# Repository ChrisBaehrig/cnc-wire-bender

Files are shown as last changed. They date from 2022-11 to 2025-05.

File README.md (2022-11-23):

# cnc-wire-bender
Open Source Project by ChrisBaehrig for a cnc controlled wire bender based on an arduino and cad fusion360 file

## Concept and changes 
The Hardware bases on the Idea of Pensas diwire bender (https://code.google.com/archive/p/diwire/ License: https://creativecommons.org/licenses/by-sa/3.0/us/) and the Project from HowtoMechatronics Wire Bender (https://howtomechatronics.com/projects/arduino-3d-wire-bending-machine/). 
Power electronic ist improved to for more durability and stronger wires. 
Software is new developed for the end to end production from the cad tool fusion 360 until the cnc wire bending

## Workflow and Architecture




## Frontend GUI Terminal
  <kbd>  </kbd>
  <kbd>   </kbd>
  <kbd>   </kbd>

## Overview GCode commands

### G1 single Axis 
Example: ```N4 G01 X10 I1500 Y2 J1200 Z9 K1300```
  - Row: 4 
  - Command: G1
  - X-Axis: Angle: +10 degree, Speed: 1500 steps / sec
  - Y-Axis: Angle: +2 degree, Speed: 1200 steps / sec
  - Z-Axis: Angle: +9 degree, Speed: 1300 steps / sec

### G2 multi Axis similstaniouly --> tbd

### G3 Circle bending 
Example: ```N4 G03 R100 Y10 Z10 L200 I1500 J1200 K1300 P0.1``` --> tbd
  - Row: 4 
  - Command: G3
  - R: Radius + 10mm clockwise, Speed: 1500 steps / sec
  - Y: Y-Angle: +10 degree, Speed: 1200 steps / sec
  - Z: Z-Angle: +10 degree, Speed: 1500 steps / sec
  - L: Absolute Lenght: 200mm
  - (Optional) Correctionfactor P0.1 = 10% overbending

Example: ```N4 G03 R100 Y10 Z10 H2.5 I1500 J1200 K1300```
  - H: count of turns (2.5 turns)

### G4 Wait 
Example: ```G04 H5```
  - Wait 5 sec

### G5 Wait for Event --> tbd

### G28 Go Home
Example: ```G28```
  - Drive to home position
  

### G92 Set all Positions to Null
Example: ```G92```
  - Set all Positions to Null to Calibrate 

### M10 Drive Wire to bender
Example: ```M10```
  - drive feeder 2000 steps 

### M11 Drive Wire for manuel cutting
Example: ```M11```
  - drive feeder 200 steps 

### M20 Pin down
Example: ```M20```
  - Moves Pin down

### M21 Pin up
Example: ```M21```
  - Moves Pin up

### M30 Program end
Example: ```M30```

## Serial connection API Commands: 

| variable 	| < 	| row 	| , 	| command 	| , 	| value1 	 | , 	| value2 	| , 	| value3 	| , 	| value4 	| > 	|
|---	|---	|-----	|---	|---	|---	|--- 	|---	|--- 	|---	|---	|---	|---	|---	|
| datatyp 	| 	| int 	| 	| int 	| 	| long 	| 	| long 	| 	| long 	| 	| float  	| 	|
| X-Axis (bend) 	| < 	| 1 	| , 	| 1 	| , 	| steps 	 | , 	| steps/sec 	| , 	| 0 	| , 	| 0.0 	| > 	|
| Y-Axis (feed) 	| < 	| 1 	| , 	| 2 	| , 	| steps 	 | , 	| steps/sec 	| , 	| 0 	| , 	| 0.0 	| > 	|
| Z-Axis (turn) 	| < 	| 1 	| , 	| 3 	| , 	| steps 	| , 	| steps/sec 	| , 	| 0 	| , 	| 0.0 	| > 	|
| p-Axis (pin) 	| < 	| 1 	| , 	| 4 	| , 	| degree 	| , 	| 0 	| , 	| 0 	| , 	| 0.0 	| > 	|
| Wait for taster	| < 	| 1 	| , 	| 5 	| , 	| 0 	 | , 	| 0 	| , 	| 0 	| , 	| 0.0 	| > 	|
| tbd 	| < 	| 1 	| , 	| 6 	| , 	| 0 	 | , 	| 0 	| , 	| 0 	| , 	| 0.0 	| > 	|
| tbd 	| < 	| 1 	| , 	| 7 	| , 	| 0 	 | , 	| 0 	| , 	| 0 	| , 	| 0.0 	| > 	|
| wait in ms 	| < 	| 1 	| , 	| 8 	| , 	| ms 	 | , 	| 0 	| , 	| 0 	| , 	| 0.0 	| > 	|
| switch debug 	| < 	| 1 	| , 	| 9 	| , 	| 1=ON 0=OFF	| , 	| 0 	| , 	| 0 	| , 	| 0.0 	| > 	|

Examples: 
```<123, 1, 100, 2000, 0, 0>```

```<1,4,160,0>``` Pin oben ```<1,4,50,0>``` Pin unten

## Changelog
### [1.0.0] - 2022-10-10

- Initial release

## Acknowledgements

Many thanks to

- [Pensas diwire bender](https://code.google.com/archive/p/diwire/) for the development the first bender
- [How to Mechatronics](https://howtomechatronics.com/projects/arduino-3d-wire-bending-machine/) for a lot of improvments

## Disclaimer
The Projekt is distributed in the hope that it will be useful, but WITHOUT ANY WARRANTY; without even the implied warranty of MERCHANTABILITY or FITNESS FOR A PARTICULAR PURPOSE.

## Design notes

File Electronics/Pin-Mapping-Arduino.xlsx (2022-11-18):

Pin Number | Pin Name | Mapped Pin Name | Anschlussbezeichnung | Farbe | Ziel | Ziel-Pin
97 | PF0 ( ADC0 ) | Analog pin 0
96 | PF1 ( ADC1 ) | Analog pin 1
95 | PF2 ( ADC2 ) | Analog pin 2
94 | PF3 ( ADC3 ) | Analog pin 3
93 | PF4 ( ADC4/TMK ) | Analog pin 4
92 | PF5 ( ADC5/TMS ) | Analog pin 5
91 | PF6 ( ADC6 ) | Analog pin 6
90 | PF7 ( ADC7 ) | Analog pin 7
89 | PK0 ( ADC8/PCINT16 ) | Analog pin 8 | potiServo_input | rot | Sub-D | 2
88 | PK1 ( ADC9/PCINT17 ) | Analog pin 9 | potiFeeder_input | orange | Sub-D | 3
87 | PK2 ( ADC10/PCINT18 ) | Analog pin 10 | potiZaxis_input | gelb | Sub-D | 4
86 | PK3 ( ADC11/PCINT19 ) | Analog pin 11 | potiBender_input | grün | Sub-D | 5
85 | PK4 ( ADC12/PCINT20 ) | Analog pin 12
84 | PK5 ( ADC13/PCINT21 ) | Analog pin 13
83 | PK6 ( ADC14/PCINT22 ) | Analog pin 14
82 | PK7 ( ADC15/PCINT23 ) | Analog pin 15
98 | AREF | Analog Reference
2 | PE0 ( RXD0/PCINT8 ) | Digital pin 0 (RX0)
3 | PE1 ( TXD0 ) | Digital pin 1 (TX0)
6 | PE4 ( OC3B/INT4 ) | Digital pin 2 (PWM)
7 | PE5 ( OC3C/INT5 ) | Digital pin 3 (PWM)
1 | PG5 ( OC0B ) | Digital pin 4 (PWM)
5 | PE3 ( OC3A/AIN1 ) | Digital pin 5 (PWM)
15 | PH3 ( OC4A ) | Digital pin 6 (PWM)
16 | PH4 ( OC4B ) | Digital pin 7 (PWM)
17 | PH5 ( OC4C ) | Digital pin 8 (PWM)
18 | PH6 ( OC2B ) | Digital pin 9 (PWM)
23 | PB4 ( OC2A/PCINT4 ) | Digital pin 10 (PWM)
24 | PB5 ( OC1A/PCINT5 ) | Digital pin 11 (PWM)
25 | PB6 ( OC1B/PCINT6 ) | Digital pin 12 (PWM)
26 | PB7 ( OC0A/OC1C/PCINT7 ) | Digital pin 13 (PWM)
64 | PJ1 ( TXD3/PCINT10 ) | Digital pin 14 (TX3) | LED_output (defekt: Spannung liegt an) | lila | Sub-D | 7
63 | PJ0 ( RXD3/PCINT9 ) | Digital pin 15 (RX3) | SchalterModus_PullUP! | blau | Sub-D | 6
13 | PH1 ( TXD2 ) | Digital pin 16 (TX2) | TasterAutomatik_PullUP! | grau | Sub-D | 8
12 | PH0 ( RXD2 ) | Digital pin 17 (RX2)
46 | PD3 ( TXD1/INT3 ) | Digital pin 18 (TX1)
45 | PD2 ( RXDI/INT2 ) | Digital pin 19 (RX1)
44 | PD1 ( SDA/INT1 ) | Digital pin 20 (SDA)
43 | PD0 ( SCL/INT0 ) | Digital pin 21 (SCL)
78 | PA0 ( AD0 ) | Digital pin 22
77 | PA1 ( AD1 ) | Digital pin 23
76 | PA2 ( AD2 ) | Digital pin 24
75 | PA3 ( AD3 ) | Digital pin 25
74 | PA4 ( AD4 ) | Digital pin 26 | Bender_PUL | - | Platine
73 | PA5 ( AD5 ) | Digital pin 27 | Bender_DIR | - | Platine
72 | PA6 ( AD6 ) | Digital pin 28 | Zaxis_PUL | - | Platine
71 | PA7 ( AD7 ) | Digital pin 29 | Zaxis_DIR | - | Platine
60 | PC7 ( A15 ) | Digital pin 30 | Feeder1_PUL | - | Platine
59 | PC6 ( A14 ) | Digital pin 31 | Feeder1_DIR | - | Platine
58 | PC5 ( A13 ) | Digital pin 32 | Feeder2_PUL | - | Platine
57 | PC4 ( A12 ) | Digital pin 33 | Feeder2_DIR | - | Platine
56 | PC3 ( A11 ) | Digital pin 34 | Feeder3_PUL | - | Platine
55 | PC2 ( A10 ) | Digital pin 35 | Feeder3_DIR | - | Platine
54 | PC1 ( A9 ) | Digital pin 36 | ServoData_output | - | Platine
53 | PC0 ( A8 ) | Digital pin 37 | Endschalter_input | - | Platine
50 | PD7 ( T0 ) | Digital pin 38
70 | PG2 ( ALE ) | Digital pin 39
52 | PG1 ( RD ) | Digital pin 40 | rs | - | LCD | 4
51 | PG0 ( WR ) | Digital pin 41 | en | - | LCD | 6
42 | PL7 | Digital pin 42 | d0 | - | LCD | 7
41 | PL6 | Digital pin 43 | d1 | - | LCD | 8
40 | PL5 ( OC5C ) | Digital pin 44 (PWM) | d2 | - | LCD | 9
39 | PL4 ( OC5B ) | Digital pin 45 (PWM) | d3 | - | LCD | 10
38 | PL3 ( OC5A ) | Digital pin 46 (PWM) | d4 | - | LCD | 11
37 | PL2 ( T5 ) | Digital pin 47 | d5 | - | LCD | 12
36 | PL1 ( ICP5 ) | Digital pin 48 | d6 | - | LCD | 13
35 | PL0 ( ICP4 ) | Digital pin 49 | d7 | - | LCD | 14
22 | PB3 ( MISO/PCINT3 ) | Digital pin 50 (MISO)
21 | PB2 ( MOSI/PCINT2 ) | Digital pin 51 (MOSI)
20 | PB1 ( SCK/PCINT1 ) | Digital pin 52 (SCK)
19 | PB0 ( SS/PCINT0 ) | Digital pin 53 (SS)
11 | GND | GND | - | schwarz | Sub-D | 10
32 | GND | GND | - | - | LCD | 1/3/5/16
62 | GND | GND
81 | GND | GND
99 | GND | GND
30 | RESET | RESET
10 | VCC | VCC | - | braun | Sub-D | 1
31 | VCC | VCC | - | - | LCD | 2/15
61 | VCC | VCC
80 | VCC | VCC
100 | AVCC | VCC
34 | XTAL1 | XTAL1
33 | XTAL2 | XTAL2
4 | PE2 ( XCK0/AIN0 )
8 | PE6 ( T3/INT6 )
9 | PE7 ( CLKO/ICP3/INT7 )
14 | PH2 ( XCK2 )
27 | PH7 ( T4 )
28 | PG3 ( TOSC2 )
29 | PG4 ( TOSC1 )
47 | PD4 ( ICP1 )
48 | PD5 ( XCK1 )
49 | PD6 ( T1 )
65 | PJ2 ( XCK3/PCINT11 )
66 | PJ3 ( PCINT12 )
67 | PJ4 ( PCINT13 )
68 | PJ5 ( PCINT14 )
69 | PJ6 ( PCINT 15 )
79 | PJ7

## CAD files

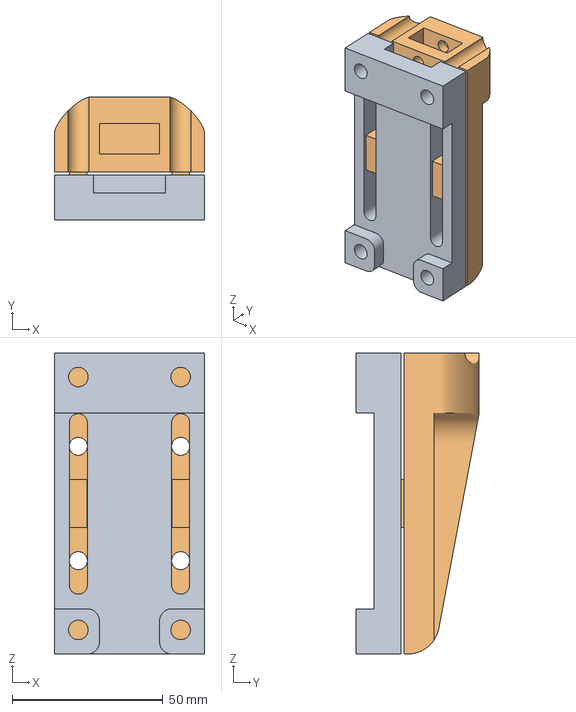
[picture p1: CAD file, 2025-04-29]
Mechanical_parts/Gegenhalter-Vorschub v8.3mf
50.0 x 41.0 x 100.0 mm
Körper1
Körper3

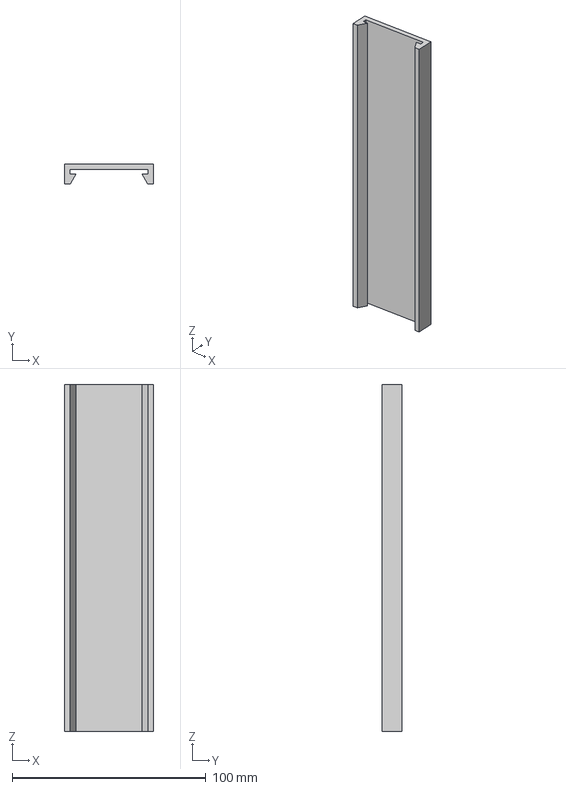
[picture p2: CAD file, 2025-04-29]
Mechanical_parts/Kabelkanaldeckel v1.3mf
46.0 x 10.5 x 179.0 mm

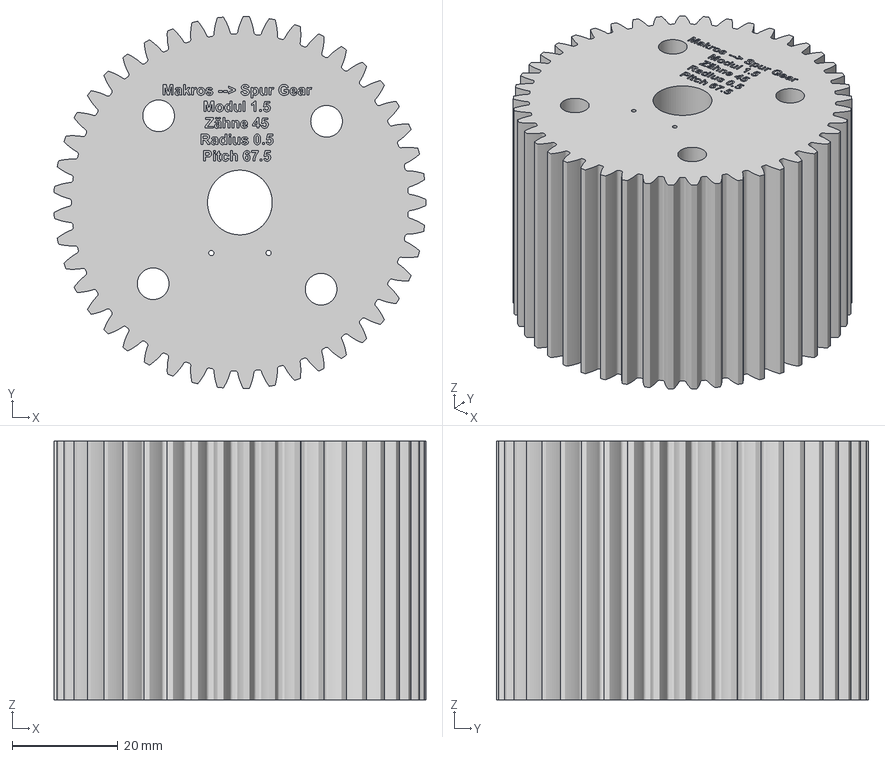
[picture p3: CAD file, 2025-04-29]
Mechanical_parts/Antriebszahnrad-Bieger v14.3mf
70.4 x 70.5 x 49.0 mm

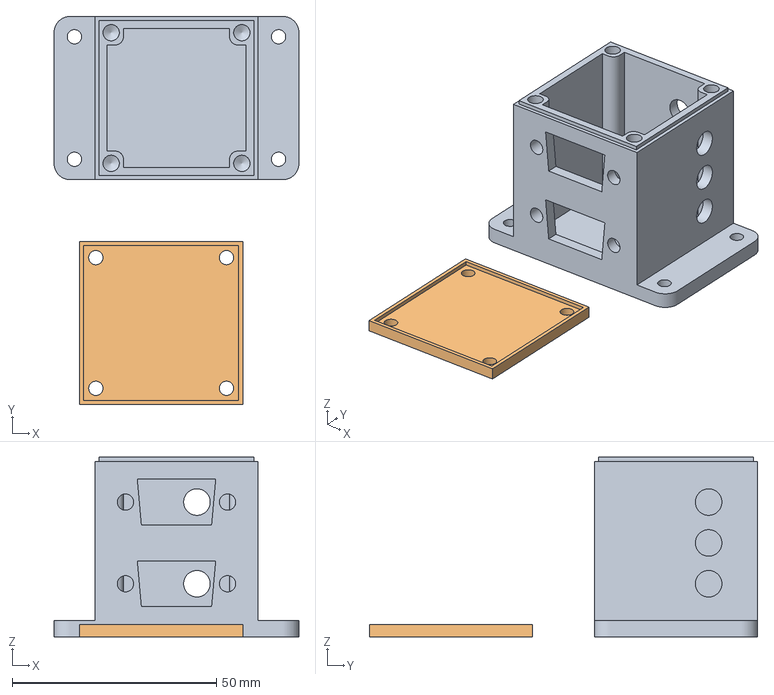
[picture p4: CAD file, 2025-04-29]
Mechanical_parts/Steckerbock-Basis v4.3mf
60.0 x 95.1 x 44.0 mm
Körper1 x 2

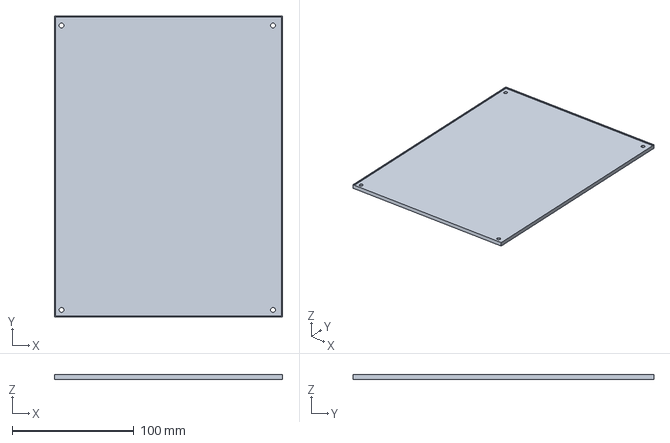
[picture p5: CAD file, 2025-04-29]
Mechanical_parts/Schaltkasten deckel v2.3mf
187.6 x 247.6 x 4.00 mm

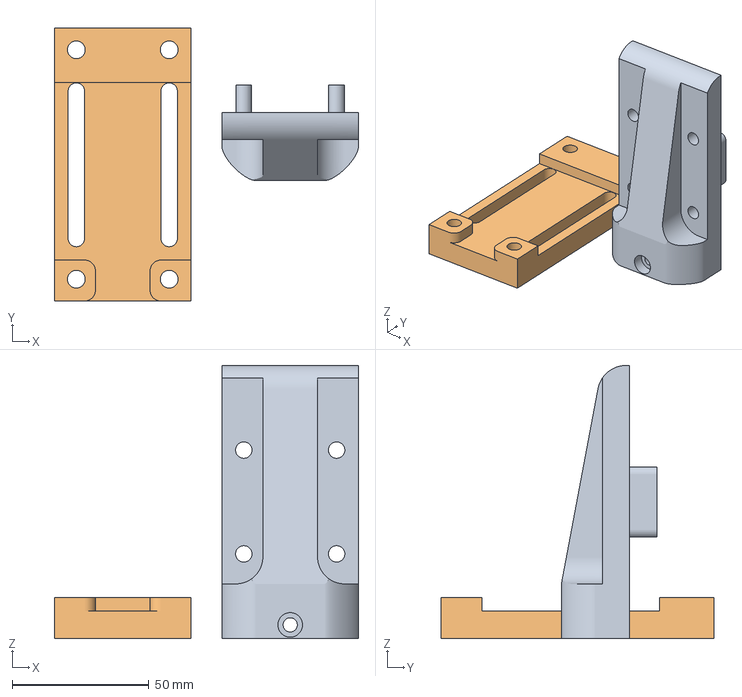
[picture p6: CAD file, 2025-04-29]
Mechanical_parts/Z-Achsengegenhalter.3mf
111.3 x 100.0 x 100.0 mm
Komponente1
Körper1

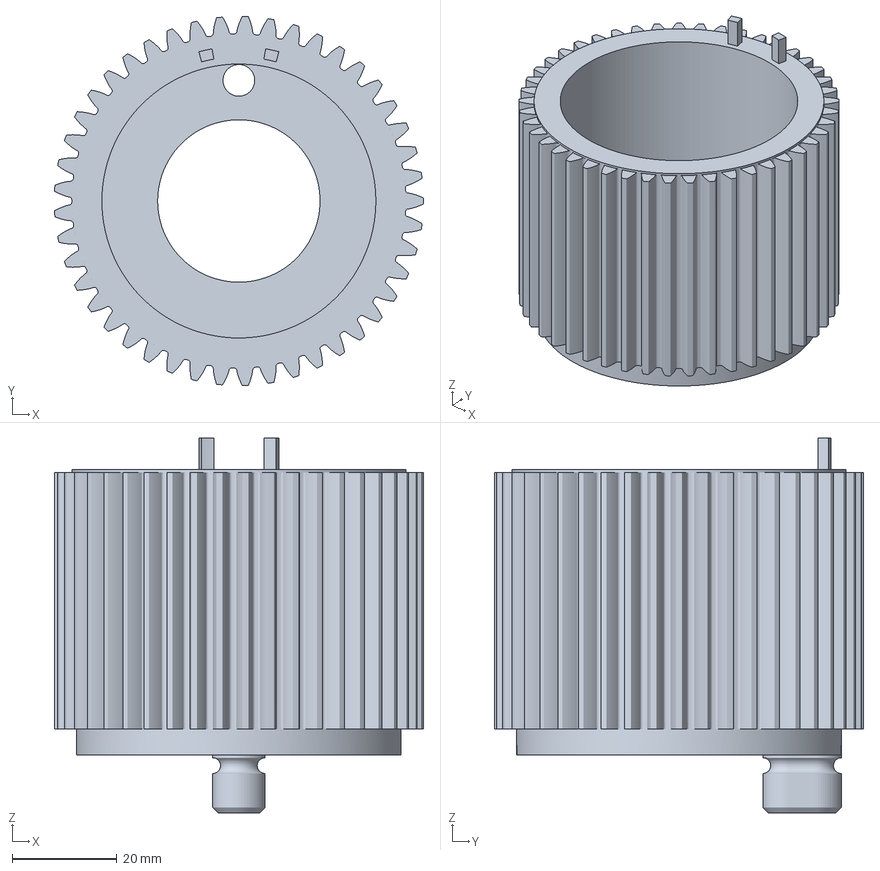
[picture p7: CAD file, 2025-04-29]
Mechanical_parts/Biegezahnrad v17.3mf
70.4 x 70.5 x 71.5 mm

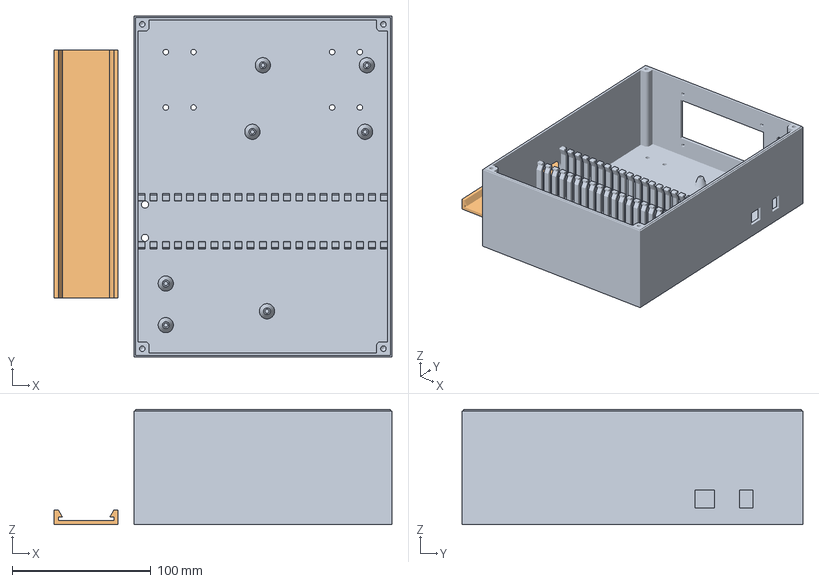
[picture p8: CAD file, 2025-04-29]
Mechanical_parts/Schaltkasten.3mf
243.5 x 246.0 x 83.0 mm
Körper1 x 2

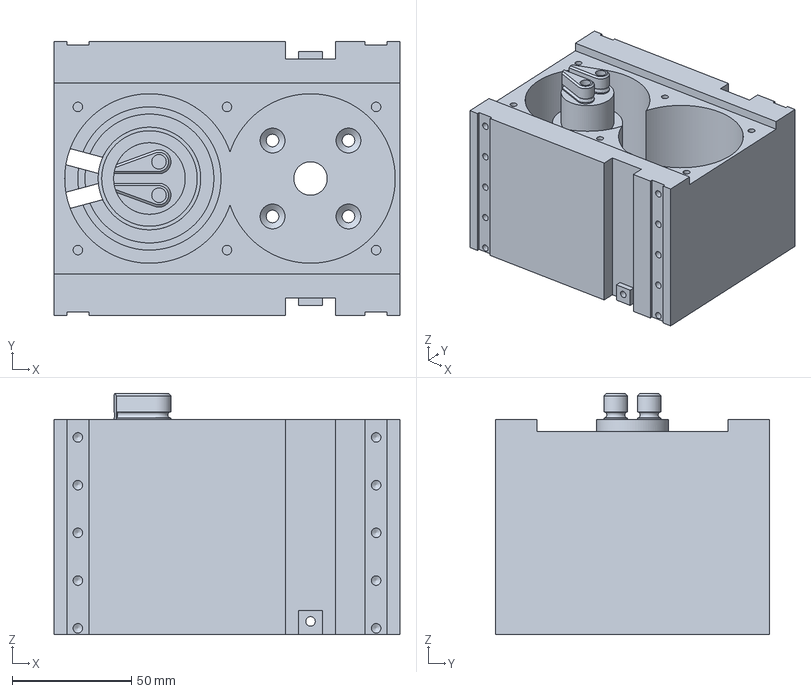
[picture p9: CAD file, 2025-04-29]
Mechanical_parts/Zahnradhalter v37.3mf
145.0 x 115.0 x 101.0 mm

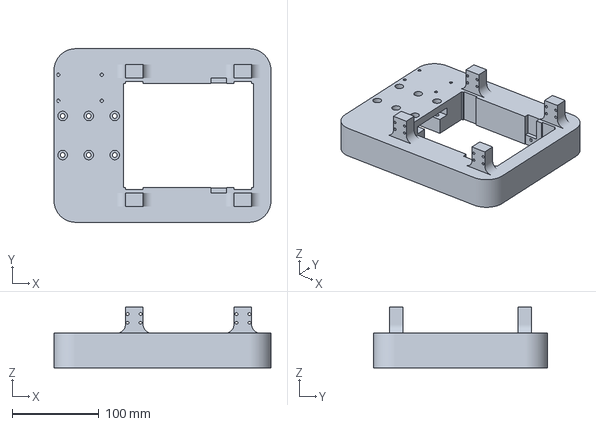
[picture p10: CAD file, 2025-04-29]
Mechanical_parts/Biegehauptplatte v29.3mf
250.0 x 200.0 x 70.0 mm

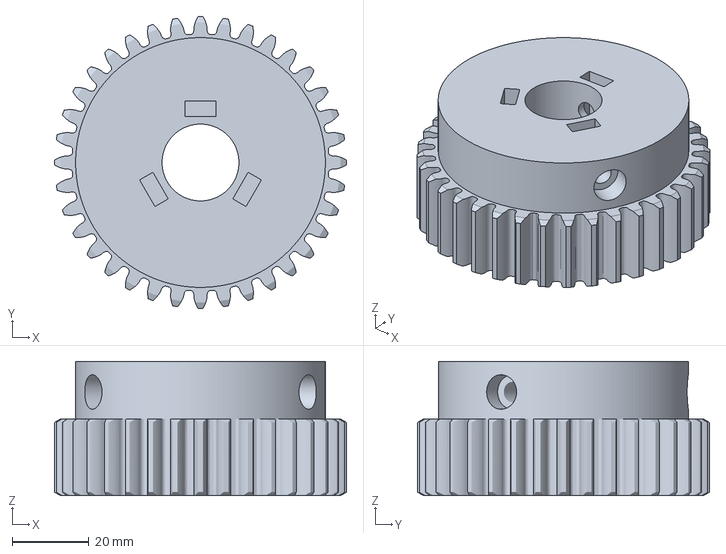
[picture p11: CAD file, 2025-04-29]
Mechanical_parts/Zahnrad Welle v2.3mf
76.0 x 76.0 x 35.0 mm

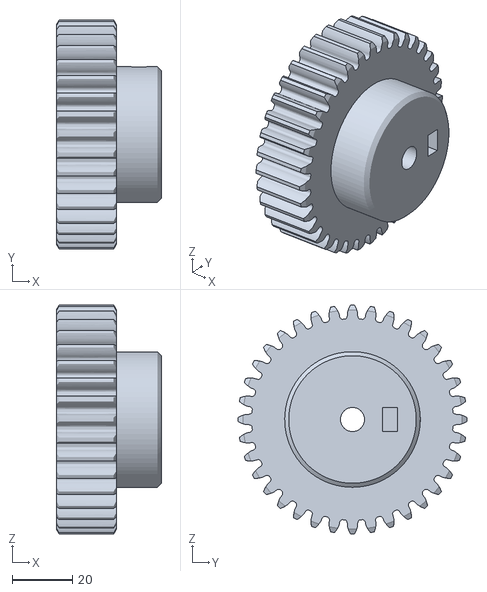
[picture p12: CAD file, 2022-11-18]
Mechanical_parts/Zahnrad Z-Motor.stl
35.0 x 76.0 x 76.0

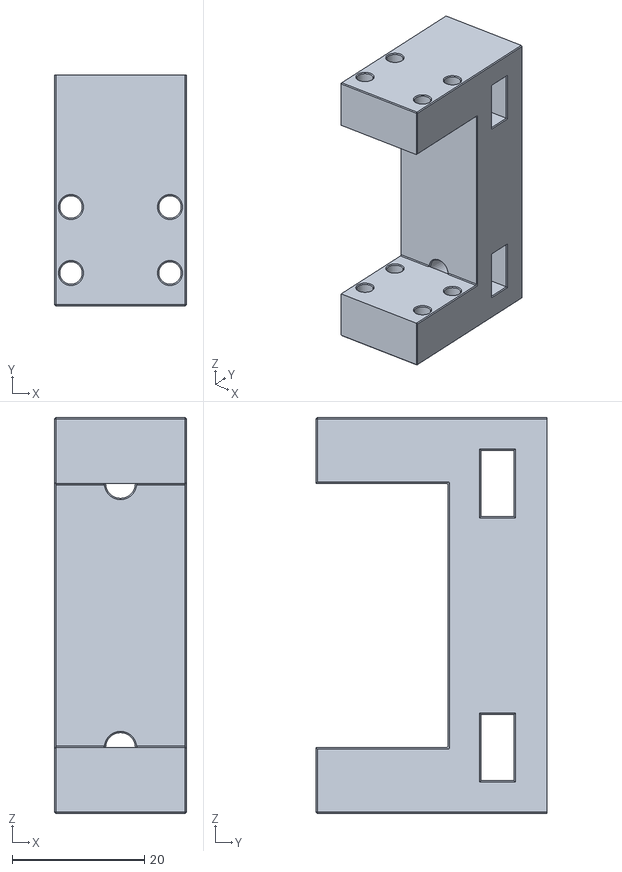
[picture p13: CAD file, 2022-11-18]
Mechanical_parts/Schlitten-Halter v4.stl
20.0 x 35.0 x 60.0

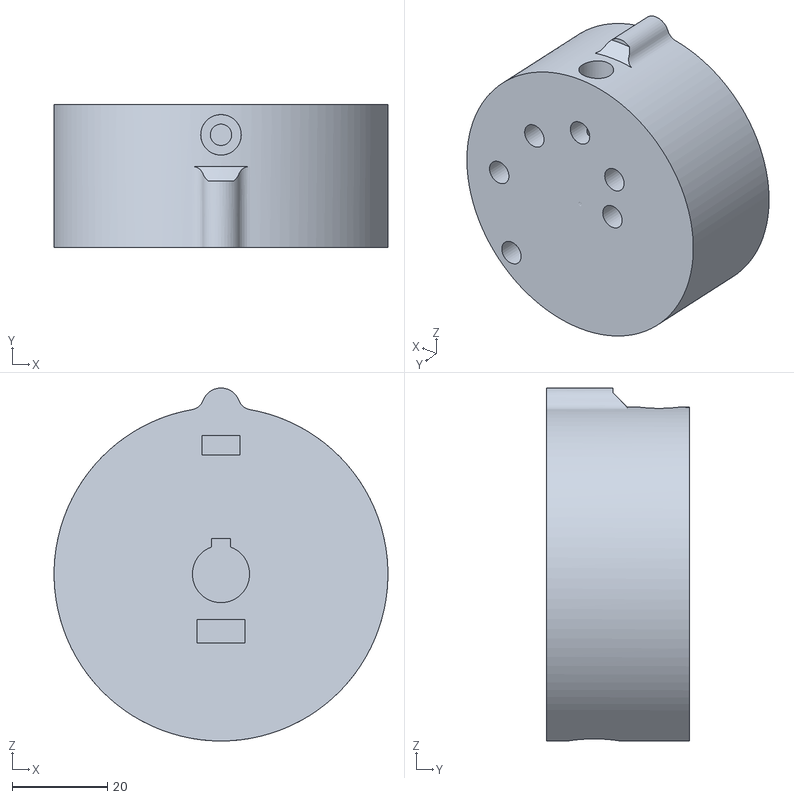
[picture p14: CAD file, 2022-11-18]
Mechanical_parts/Biegerad v5.stl
70.0 x 30.0 x 74.0

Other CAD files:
Mechanical_parts/Schlitten-Halter-Heber v2.stl
Mechanical_parts/Düse v5.stl
Mechanical_parts/Gegenhalter-Vorschub v6.3mf

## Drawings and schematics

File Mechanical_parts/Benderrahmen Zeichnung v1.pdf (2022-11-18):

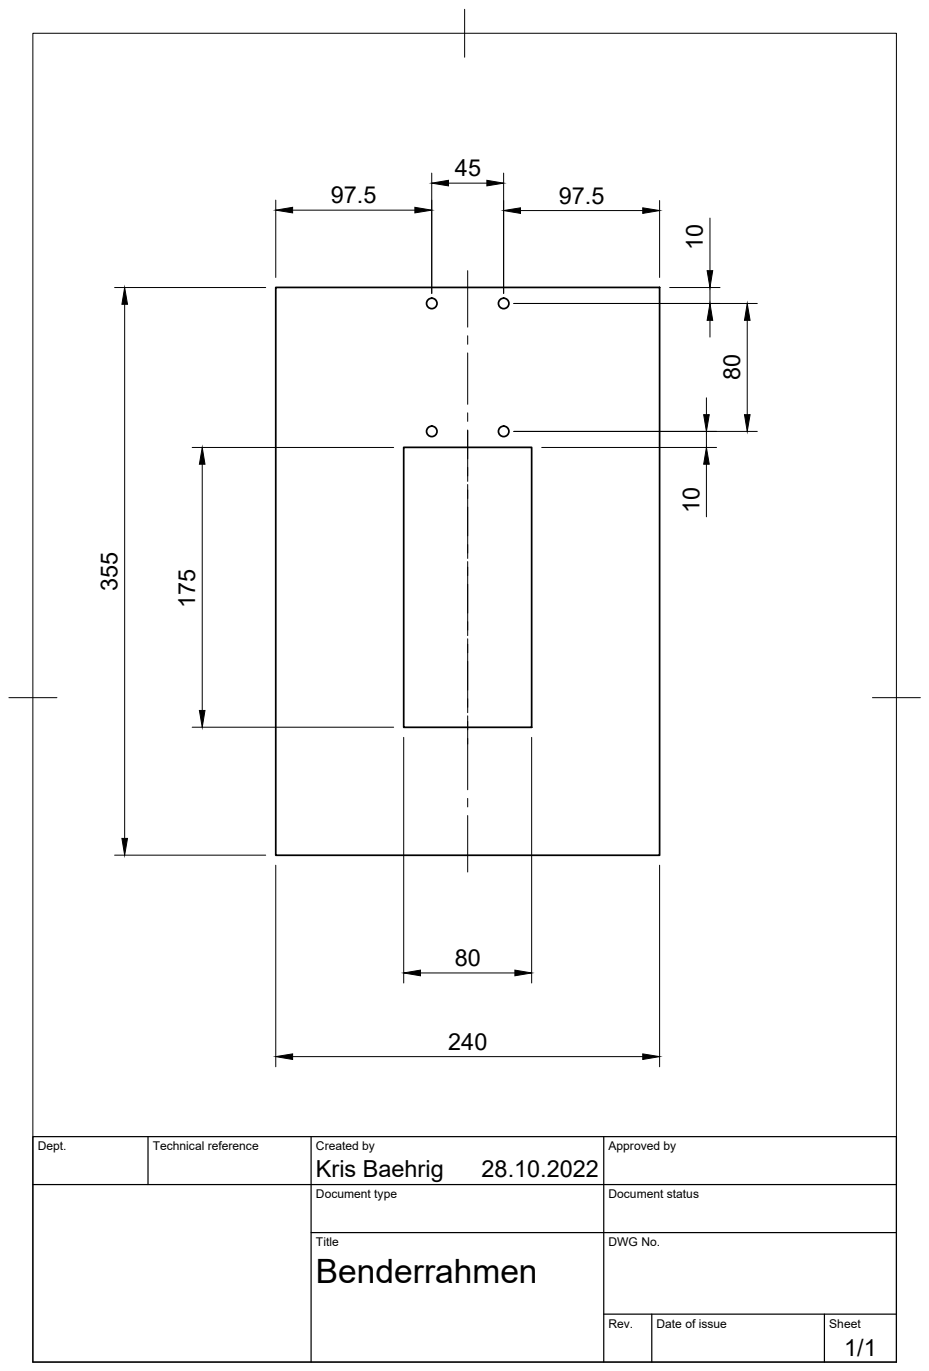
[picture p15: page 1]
Kris Baehrig 355

Dept. | Technical reference | Created by 28.10.2022 | Approved by

Document type | Document status

Title Benderrahmen | DWG No.

Rev. | Date of issue | Sheet 1/1

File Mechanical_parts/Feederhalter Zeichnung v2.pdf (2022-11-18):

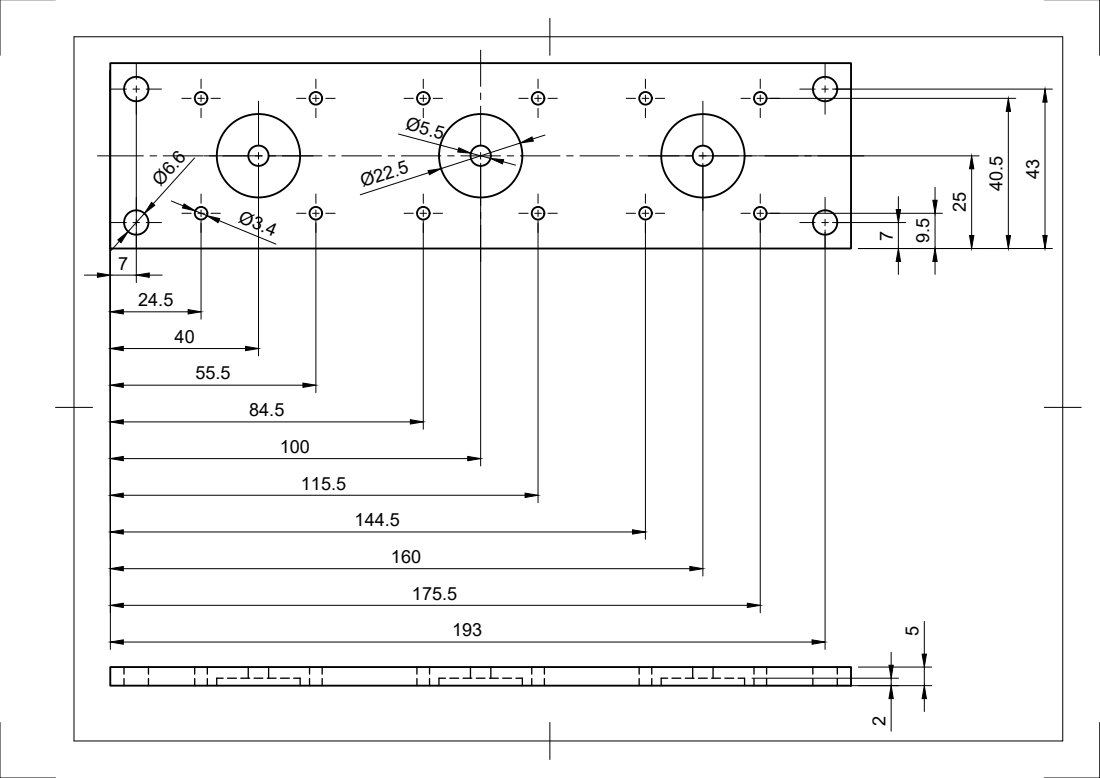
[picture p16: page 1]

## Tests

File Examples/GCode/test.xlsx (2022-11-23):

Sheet: calculation
 | row | command | value1 | value2 | g_code
N | 1 | G92 |  |  | N1 G92
N | 2 | G01 | X45 | I4000 | N2 G01 X45 I4000
N | 3 | M21 |  |  | N3 M21
N | 4 | G01 | X-45 | I4000 | N4 G01 X-45 I4000
N | 5 | G01 | X-20 | I4000 | N5 G01 X-20 I4000
N | 6 | M20 |  |  | N6 M20
N | 7 | G01 | Z100 | K2000 | N7 G01 Z100 K2000
N | 8 | G01 | X-45 | I4000 | N8 G01 X-45 I4000
N | 9 | M21 |  |  | N9 M21
N | 10 | G01 | X45 | I4000 | N10 G01 X45 I4000
N | 11 | G01 | X20 | I4000 | N11 G01 X20 I4000
N | 12 | M20 |  |  | N12 M20
N | 13 | G01 | Z100 | K2000 | N13 G01 Z100 K2000
N | 14 | G01 | X45 | I4000 | N14 G01 X45 I4000
N | 15 | M21 |  |  | N15 M21
N | 16 | G01 | X-45 | I4000 | N16 G01 X-45 I4000
N | 17 | G01 | X-20 | I4000 | N17 G01 X-20 I4000
N | 18 | M20 |  |  | N18 M20
N | 19 | G01 | Z100 | K2000 | N19 G01 Z100 K2000
N | 20 | G01 | X-45 | I4000 | N20 G01 X-45 I4000
N | 21 | M21 |  |  | N21 M21
N | 22 | G01 | X45 | I4000 | N22 G01 X45 I4000
N | 23 | G01 | X20 | I4000 | N23 G01 X20 I4000
N | 24 | M20 |  |  | N24 M20
N | 25 | G01 | Z100 | K2000 | N25 G01 Z100 K2000
N | 26 | G01 | X45 | I4000 | N26 G01 X45 I4000
N | 27 | M30 |  |  | N27 M30
N | 28 |  |  |  | N28
N | 29 |  |  |  | N29
N | 30 |  |  |  | N30
N | 31 |  |  |  | N31
N | 32 |  |  |  | N32
N | 33 |  |  |  | N33
N | 34 |  |  |  | N34

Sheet: GCODE
g_code
N1 G92
N2 G01 X90 I4000
N3 M21
N4 G01 X-90 I4000
N5 G01 X-20 I4000
N6 M20
N7 G01 Z100 K2000
N8 G01 X-90 I4000
N9 M21
N10 G01 X90 I4000
N11 G01 X20 I4000
N12 M20
N13 G01 Z100 K2000
N14 G01 X90 I4000
N15 M21
N16 G01 X-90 I4000
N17 G01 X-20 I4000
N18 M20
N19 G01 Z100 K2000
N20 G01 X-90 I4000
N21 M21
N22 G01 X90 I4000
N23 G01 X20 I4000
N24 M20
N25 G01 Z100 K2000
N26 G01 X90 I4000
N27 M30

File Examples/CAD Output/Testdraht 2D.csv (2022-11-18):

Zeile | X-Koordinate | Y-Koordinate | Z-Koordinate | X-Vektor | Y-Vektor | Z-Vektor
0 | 0,0 | 0,0 | 0,0 | 1,0 | 0,0 | 0,0
1 | 0,21260642982231376 | 0,0 | 0,0 | 1,0 | 0,0 | 0,0
2 | 0,4252128596446275 | 0,0 | 0,0 | 1,0 | 0,0 | 0,0
3 | 0,6378192894669412 | 0,0 | 0,0 | 1,0 | 0,0 | 0,0
4 | 0,850425719289255 | 0,0 | 0,0 | 1,0 | 0,0 | 0,0
5 | 1,0630321491115688 | 0,0 | 0,0 | 1,0 | 0,0 | 0,0
6 | 1,2756385789338824 | 0,0 | 0,0 | 1,0 | 0,0 | 0,0
7 | 1,4882450087561963 | 0,0 | 0,0 | 1,0 | 0,0 | 0,0
8 | 1,70085143857851 | 0,0 | 0,0 | 1,0 | 0,0 | 0,0
9 | 1,9134578684008232 | 0,0 | 0,0 | 1,0 | 0,0 | 0,0
10 | 2,1260642982231377 | 0,0 | 0,0 | 1,0 | 0,0 | 0,0
11 | 2,3386707280454506 | 0,0 | 0,0 | 1,0 | 0,0 | 0,0
12 | 2,5461424962999892 | 0,0 | -0,02236553049228168 | 0,8998645443451205 | 0,0 | -0,43616946457833194
13 | 2,7374594843968882 | 0,0 | -0,11509796315379092 | 0,8998645443451205 | 0,0 | -0,43616946457833194
14 | 2,9287764724937877 | 0,0 | -0,2078303958153003 | 0,8998645443451205 | 0,0 | -0,43616946457833194
15 | 3,1200934605906863 | 0,0 | -0,3005628284768093 | 0,8998645443451205 | 0,0 | -0,43616946457833194
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

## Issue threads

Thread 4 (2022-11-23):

Tab Manuel

ChrisBaehrig, 2022-11-23:
label degree.. is missing
Z-Axis 100 = 2,4cm why

Closed 2025-05-06.

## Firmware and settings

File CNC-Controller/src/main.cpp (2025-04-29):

//------------------------
//Release V4.1 IO
//------------------------

//Releses:
//V1.0 Serielle Schnittstelle empfängt CHAR und schreibt die Zeichen wieder auf die Serielle Schnittstelle und das LCD
//V1.1 Auswerten der Empfangenen CHAR auf Schnittstelle und speichern von Parameter und Attribut
//V1.2 Übergabe erweitern und testen und einbinden der Zeilennummer 
//V2.0 Einbinden ein Stepper mit eigener Funktion und test. Versuch hat die Bib Accelstepper ausgeschlossen.
//V2.1 Erweiterung alle Stepper änderung value_1 auf long
//V2.2 Einbinden Servosteuerung
//V2.21 Anpassungen an Python Terminal
//V2.22 Debugging nach erstem Test ( Drehrichtung Z, Servo eistellungen,
//V2.3 Freigabeschalter einbinden display erweitert (Zeile 1: row, command / Zeile 2: value_1, value_2 / Zeile 3: value_3, value_4 / Zeile: 4: Status, Kommentar)
//V2.4 Stop mit Kippschalter
//V2.5 Pin UP DOWN optimieren
//V3.0 Debug, 
//V4.0 Neuer Biegekopf installiert mit Servoansteuerung
//V4.1 Verbesserte Servo ansteuerung mit grad

/*Releasplanung:  
//V5.0 Überarbeiteter Benderkopf und elektronik in code einbinden

*/
#include <Arduino.h>
#include <Servo.h>
#include <LiquidCrystal.h> 

// Function prototypes
void getDataFromPC();
void parseData();
void replyToPC();
void showCommandLCD();
void run_stepper(int pin_pul, int pin_dir, int steps, int stepper_speed);
void move_pin(int pin_target);
void wait_taster(int input_pin);
void LockMotor();
void DebugMode(int mode);

// Global variables and objects
char prog_version[20] = "V5.0 Work";

//Config LCD
const int rs = 40, en = 41, d4 =46, d5 = 47, d6= 48, d7 = 49;
LiquidCrystal lcd(rs, en, d4, d5, d6, d7);

//Config Serial
const byte buffSize = 40;
char inputBuffer[buffSize];
const char startMarker = '<';
const char endMarker = '>';
byte bytesRecvd = 0;
bool readInProgress = false;
bool newDataFromPC = false;

//Config Recaived Data
int row = 0;
int command = 0;
long value_1 = 0;
long value_2 = 0;
long value_3 = 0;
long value_4 = 0;

//Config Hardware,Pins
const int xaxis_pul = 2;
const int xaxis_dir = 3;
const int yaxis_pul = 4;
const int yaxis_dir = 5;
const int zaxis_pul = 6;
const int zaxis_dir = 7;
const int move_pin_out1 = 18;
const int move_pin_out2 = 19;
const int button_next_step = 15;  
const int switch_debug_mode = 16;
const byte interrupt_pin_switch1 = 20;
const byte interrupt_pin_switch2 = 21;

volatile int motor_lock = 0;
byte debug_mode = true;

//Config Stepper
const int pulse_width = 20;
int pulse_delay = 500;

// Function definitions
void LockMotor() {
  if (digitalRead(interrupt_pin_switch1) == HIGH) {
    motor_lock = 1;
    Serial.println("Secure switch 1 --> Motor locked"); 
    lcd.setCursor(0, 3);
    lcd.print("Secure switch 1");
  }
  else if (digitalRead(interrupt_pin_switch2) == HIGH) {
    motor_lock = 2;
    Serial.println("Secure switch 2 --> Motor locked"); 
    lcd.setCursor(0, 3);
    lcd.print("Secure switch 2");
  }
  else {
    motor_lock = 0;
    Serial.println("Motor-Free"); 
    lcd.setCursor(0, 3);
    lcd.print("Free ");
  }
}

void getDataFromPC() {
  // receive data from PC and save it into inputBuffer
  //Beispiel aus https://forum.arduino.cc/index.php?topic=225329.msg1810764#msg1810764
    
  if(Serial.available() > 0) {
    char x = Serial.read();

    // the order of these IF clauses is significant   
    if (x == endMarker) {
      readInProgress = false;
      newDataFromPC = true;
      inputBuffer[bytesRecvd] = 0;
      parseData();
    }
    
    if(readInProgress) {
      inputBuffer[bytesRecvd] = x;
      bytesRecvd ++;
      if (bytesRecvd == buffSize) {
        bytesRecvd = buffSize - 1;
      }
    }

    if (x == startMarker) { 
      bytesRecvd = 0; 
      readInProgress = true;
    }
  }
}

//--------------------------------------------------------------------------------------------------------------
//=====================================================SETUP==================================================
//--------------------------------------------------------------------------------------------------------------  
void setup() {
  //Config Pins
  pinMode(xaxis_pul, OUTPUT); 
  pinMode(xaxis_dir, OUTPUT); 
  pinMode(yaxis_pul, OUTPUT); 
  pinMode(yaxis_dir, OUTPUT);
  pinMode(zaxis_pul, OUTPUT); 
  pinMode(zaxis_dir, OUTPUT);
  pinMode(move_pin_out1, OUTPUT);
  pinMode(move_pin_out2, OUTPUT);
  pinMode(button_next_step, INPUT_PULLUP); 
  pinMode(switch_debug_mode, INPUT_PULLUP);
  pinMode(interrupt_pin_switch1, INPUT_PULLUP);
  pinMode(interrupt_pin_switch2, INPUT_PULLUP);

  //Interrupt
  attachInterrupt(digitalPinToInterrupt(interrupt_pin_switch1), LockMotor, RISING);
  attachInterrupt(digitalPinToInterrupt(interrupt_pin_switch2), LockMotor, RISING);

  //Config Serial
  Serial.begin(9600); // set the baud rate
  Serial.println("-*-*-*-*-*-*-*-NEW CONNECTION-*-*-*-*-*-*-*-");
  Serial.print("Version: ");   
  Serial.println(prog_version); 
  Serial.println("<Arduino is ready>"); 

  //Config Display
  lcd.begin(20, 4); // Achtung HiL hat nur (16, 2), alle anderen Zeichen werden auf HiL abgeschnitten
  lcd.clear();
  lcd.setCursor(0, 0);
  lcd.print("Version: ");
  lcd.setCursor(9, 0);
  lcd.print(prog_version);
  lcd.setCursor(0, 1);
  lcd.print("Arduino is ready"); 


}
//--------------------------------------------------------------------------------------------------------------
//=====================================================LOOP=================================
//

void loop() {

  getDataFromPC();

  if (newDataFromPC) {   
    //Debug Mode from switch
    DebugMode(digitalRead(switch_debug_mode));
    showCommandLCD();
  
    switch (command) { //TODO: byte wäre auch möglich statt integer
      case 1: //Bender (X-Achse)
        if (debug_mode == true){
          wait_taster(button_next_step); 
        }
        run_stepper(xaxis_pul, xaxis_dir, value_1, value_2);
        break;
  
      case 2: //Turn (Y-Achse)
        if (debug_mode == true){
          wait_taster(button_next_step); 
        }
        run_stepper(yaxis_pul, yaxis_dir, value_1, value_2);
        break;

      case 3: //Feeder (Z-Achse)
        if (debug_mode == true){
          wait_taster(button_next_step); 
        }
        run_stepper(zaxis_pul, zaxis_dir, value_1 * -1, value_2); //value_1 invent because different turning direction
        break;

      case 4: //Linear Motor Pin move up = 1 down = 0
        if (debug_mode == true){
          wait_taster(button_next_step); 
        }
        move_pin(value_1);
        break;

      case 5: //Wait for taster
        wait_taster(button_next_step);
        break;

      case 8: //Wait in ms
        lcd.setCursor(0, 3);
        lcd.print("Wait ms");
        Serial.println("Wait ms");
        delay(value_1); //wait in ms (1000 = 1 second) 
        break;

      case 9: //Change Debug Mode
        DebugMode(value_1);
        break;
          
      default:
        Serial.println("Error: Wrong Command at Seriel in");  
        break;    
    }
    replyToPC(); 
  }
  
  newDataFromPC = false;
}

//============FUNCTIONS=============================

void parseData() {                         // split the data into its parts
    
  char * strtokIndx;                       // this is used by strtok() as an index

  strtokIndx = strtok(inputBuffer,",");    // get the first part - the string
  row = atoi(strtokIndx);                  // convert this part to an integer
  
  strtokIndx = strtok(NULL, ",");          // this continues where the previous call left off
  command = atoi(strtokIndx);              // convert this part to an integer
  
  strtokIndx = strtok(NULL, ",");          // this continues where the previous call left off
  value_1 = atol(strtokIndx);              // convert this part to an integer

  strtokIndx = strtok(NULL, ",");          // this continues where the previous call left off
  value_2 = atol(strtokIndx);              // convert this part to an integer

  strtokIndx = strtok(NULL, ",");          // this continues where the previous call left off
  value_3 = atol(strtokIndx);              // convert this part to an integer
  
  strtokIndx = strtok(NULL, ",");          // this continues where the previous call left off
  //value_4 = atof(strtokIndx);            // for float; Beim Test sind Fehler aufgefallen. sind zu vermeiden. 
  value_4 = atol(strtokIndx);              // convert this part to an integer
}

//=============

void replyToPC() {
  Serial.print("<");
  Serial.print(row);
  Serial.print(", ");
  Serial.print(command);
  Serial.print(", ");
  Serial.print(value_1);
  Serial.print(", ");
  Serial.print(value_2);  
  Serial.print(", ");
  Serial.print(value_3);
  Serial.print(", ");
  Serial.print(value_4); 
  Serial.print(">");
  Serial.println();  // Add newline after the closing bracket
}

//============

void showCommandLCD() { // Bei Text lcd.write sonst lcd.print 
  lcd.clear();
  lcd.setCursor(0, 0);
  lcd.print("Row");
  lcd.setCursor(3, 0);
  lcd.print(row);
  lcd.setCursor(8, 0);
  lcd.print("Com");
  lcd.setCursor(11, 0);
  lcd.print(command);
  lcd.setCursor(0, 1);
  lcd.print(value_1);
  lcd.setCursor(9, 1);
  lcd.print(value_2);
  lcd.setCursor(0, 2);
  lcd.print(value_3);
  lcd.setCursor(9, 2);
  lcd.print(value_4);
}

//============

void run_stepper(int pin_pul, int pin_dir, int steps, int stepper_speed) { //Max. 6kHZ möglich
  Serial.println("Stepper is running");
  Serial.print("Status Motorlock before running: ");
  Serial.println(motor_lock); 
  

  //Output Direktion 
  if (steps > 0) {
    digitalWrite(pin_dir, HIGH);
  }
  else {
    digitalWrite(pin_dir, LOW);
  }
  //Calculation delay from frequancy
  pulse_delay = (1000000 / stepper_speed) - pulse_width; //Example:1/2000*1000000-20=480

  long steps_abs = abs(steps) ;
  
  int i = 0;
  while (i < steps_abs && motor_lock == 0) {
    digitalWrite(pin_pul, HIGH);
    delayMicroseconds (pulse_width); 
    digitalWrite(pin_pul, LOW);
    delayMicroseconds (pulse_delay); 
    i++;
  }
  Serial.print("Status Motorlock after stopping: ");
  Serial.println(motor_lock); 
  
  delay(10);
}

//============

void move_pin (int pin_target) {
  Serial.print("Bender Pin is moving to target: ");
  Serial.println(pin_target);  

  if (pin_target == 1){
    digitalWrite(move_pin_out1, LOW);
    digitalWrite(move_pin_out2, HIGH);
  }
  else {
    digitalWrite(move_pin_out1, HIGH);
    digitalWrite(move_pin_out2, LOW);
  }

  delay(1000);
}


void wait_taster (int input_pin){
  lcd.setCursor(0, 3);
  lcd.print("Wait for taster  ");
  Serial.println("Wait for taster");
  
  while(digitalRead(input_pin)==HIGH){}  //wait until taster
  lcd.setCursor(0, 3);
  lcd.print("Taster is pressed"); 
  Serial.println("Taster pressed"); 

  motor_lock = false;
  Serial.println("Motor-Free"); 
  lcd.setCursor(15, 0);
  lcd.print("Free");

}

void DebugMode(int mode){
  if (mode == 1){
    debug_mode = true;
    Serial.println("DEBUG MODE: ON"); 
    lcd.setCursor(11, 3);
    lcd.print("Debug ON");
  }
  else {
    debug_mode = false;
    Serial.println("DEBUG MODE: OFF"); 
    lcd.setCursor(11, 3);
    lcd.print("Debug OFF");
  }
}

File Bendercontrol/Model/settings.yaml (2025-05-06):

home_position:
  left: 10.0
  right: -10.0
p_axis:
  name: Pin
  number: 4
  pin_down: 0
  pin_up: 1
port: COM4
position:
  p: 0
  x: 0.0
  y: 0
  z: 0
x_axis:
  angle_max: 135.0
  angle_min: -135.0
  max_speed: 6000
  name: Bender
  number: 1
  steps_per_round: 18462
  work_speed: 2000
y_axis:
  angle_max: 720
  angle_min: -720
  max_speed: 5000
  name: Y-Achse
  number: 2
  steps_per_round: 10700
  work_speed: 1500
z_axis:
  angle_max: 1000.0
  angle_min: -1000.0
  max_speed: 5000
  name: Feeder
  number: 3
  steps_per_mm: 27.8468085
  work_speed: 1500

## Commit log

2022-11-18 testing bugfixing
    [GCODE_20-05-12_Test-G01.xlsx, GCODE_20-05-20_Test-G03_2Halbkreise.xlsx, test.xlsx]
2022-11-23 smal changes
    [test.xlsx]
2025-04-28 Fix for Arduino Connection
    [Settings.py, main.cpp, settings.yaml]
2025-04-29 GUI: Entfernung der Einheiten auf der Einrichten-Seite, Anpassung der Achsenbereiche und Aktualisierung der mechanischen Teile
    [Antriebszahnrad-Bieger v14.3mf, Biegehauptplatte v29.3mf, Biegezahnrad v17.3mf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]
2025-05-06 fix: X-axis now uses integer steps instead of float for consistent step-based movement
    [InterpreterToCommand.py, settings.yaml]
